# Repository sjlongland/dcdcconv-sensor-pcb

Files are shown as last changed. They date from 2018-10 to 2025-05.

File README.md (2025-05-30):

[Find this project on codeberg](https://codeberg.org/sjlongland/dcdcconv-sensor-pcb)

As a result of Github's decision to force AI-generated issues with no opt-out,
I am migrating personal projects of mine to Codeberg.  The project at Github
will be archived.

----

# Voltage/Current sensor board

This is a differential I²C voltage and current sensing board using the TI
INA219 power monitor IC and the NXP PCA9615 differential I²C controller.  This
is intended to provide a high-accuracy voltage and current measurement for the
[DC-DC converter
controller](https://codeberg.org/sjlongland/dcdcconv-controller-pcb).

There is a footprint for an on-board current shunt (e.g. TT Electronics
LRMAP5930B-R0002FT) as well as a connector for an off-board one.  The board
also has footprints for two screw terminal blocks (Phoenix Contact "Combicon"
1706785) to interface the board to up to 6AWG cables for power input/output.

Four two-way jumpers allow full freedom in selecting the I²C address used by
the INA219 according to combinations of settings chosen from its data sheet.

The underside has exposed copper areas to allow additional stranded cable to
be soldered over the traces to enhance the current carrying capability.

## Parts list

* C1, C3: 100nF ≥10V ceramic capacitor 0805 SMD (localised decoupling)
* C2: ≥100µF ≥10V electrolytic capacitor 6.3mm SMD (bulk decoupling)
* (**FIT ONE ONLY**) C4, C5, C6, C7: 100pF ≥20V ceramic capacitor (0V AC
  decoupling capacitor to chassis.  Choose the capacitor that best suits your
  mounting arrangements.)
* U1: NXP PCA9615 differential I²C controller.
* U2: TI INA219BIDR power monitor.
* R1, R6: (**NOT CONFIRMED**) 2k2 ohm 0805 SMD resistors (differential I²C
  pull-up)
* R4, R9: Spaces for additional pull-ups for differential I²C, do not fit
  unless found to be required.
* R5, R10: (**NOT CONFIRMED**) 2k2 ohm 0805 SMD resistors (differential I²C
  pull-down)
* R2, R7: Spaces for additional pull-downs for differential I²C, do not fit
  unless found to be required.
* R3, R8: (**NOT CONFIRMED**) 100 ohm 0805 SMD resistors (differential I²C
  termination)
* R12, R13: (**NOT CONFIRMED**) 2k2 ohm 0805 SMD resistors (I²C pull-up)
* J1: 6-pin 2.54mm "KK" connector (differential I²C bus)
* J2: 2-pin 2.54mm "KK" connector (external current shunt, **omit if fitting
  R11)

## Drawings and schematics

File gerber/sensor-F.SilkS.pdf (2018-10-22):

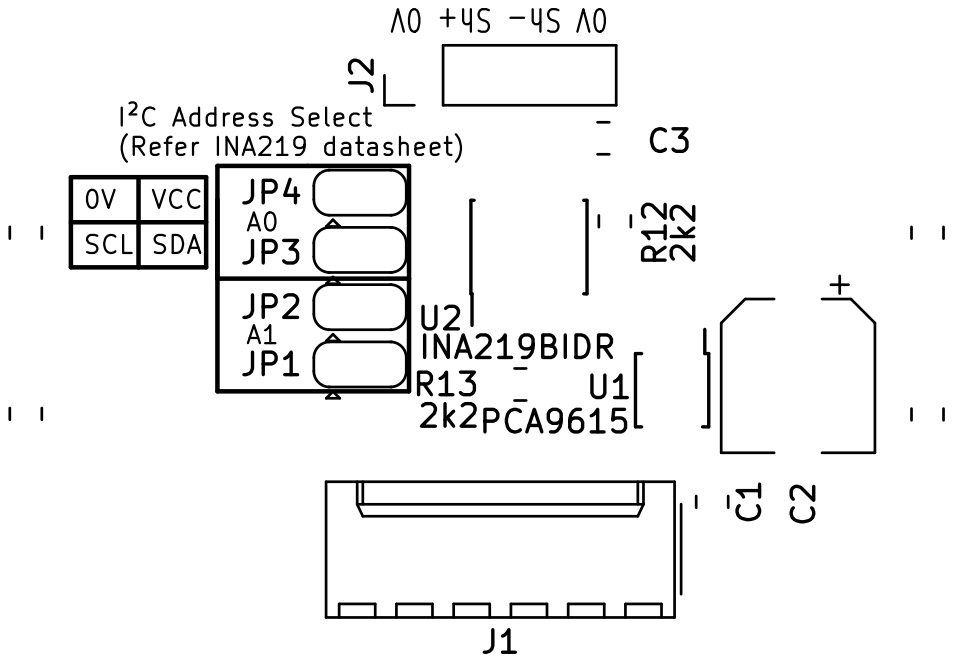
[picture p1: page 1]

0V | VCC | A1 A0 JP3
SCL | SDA

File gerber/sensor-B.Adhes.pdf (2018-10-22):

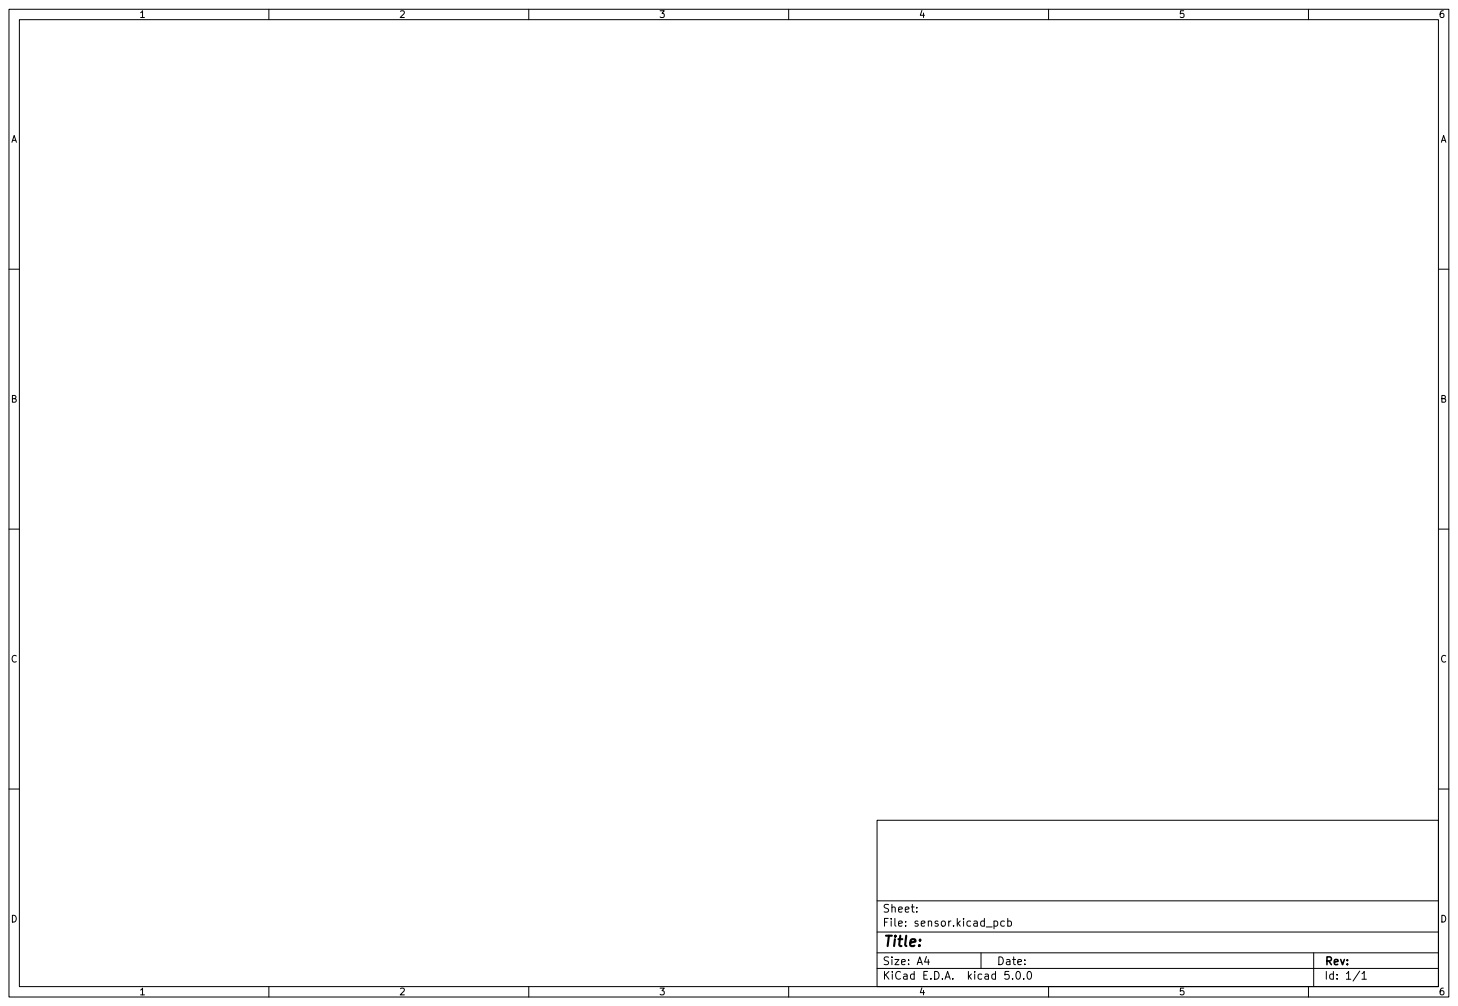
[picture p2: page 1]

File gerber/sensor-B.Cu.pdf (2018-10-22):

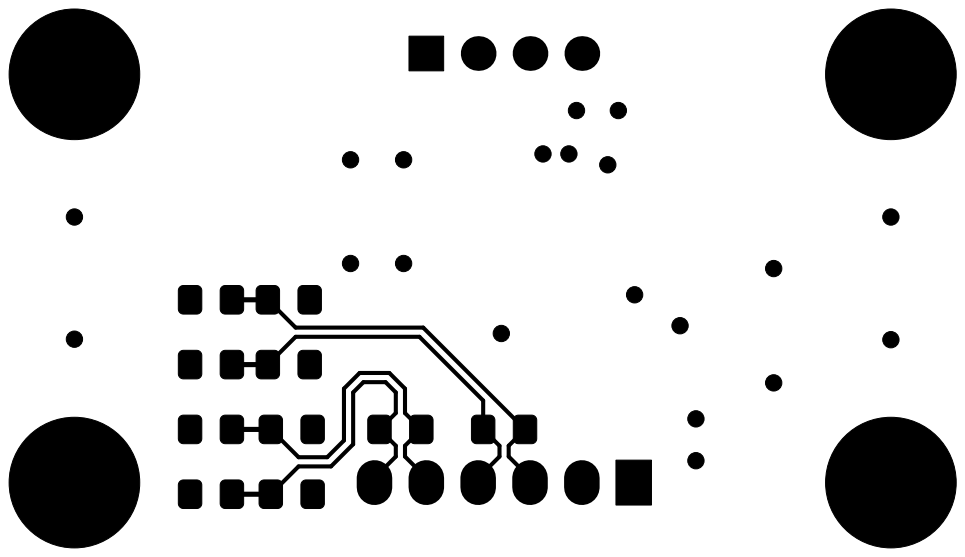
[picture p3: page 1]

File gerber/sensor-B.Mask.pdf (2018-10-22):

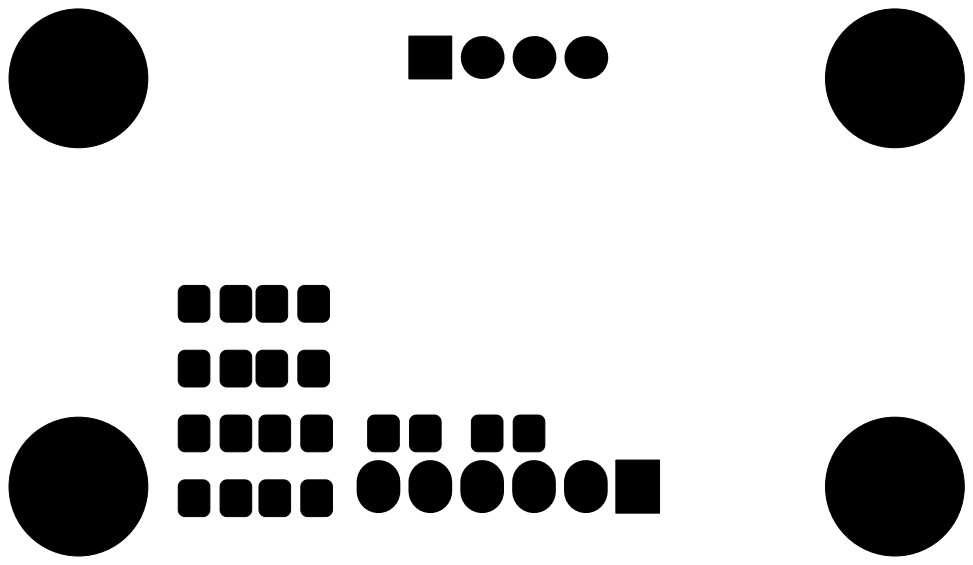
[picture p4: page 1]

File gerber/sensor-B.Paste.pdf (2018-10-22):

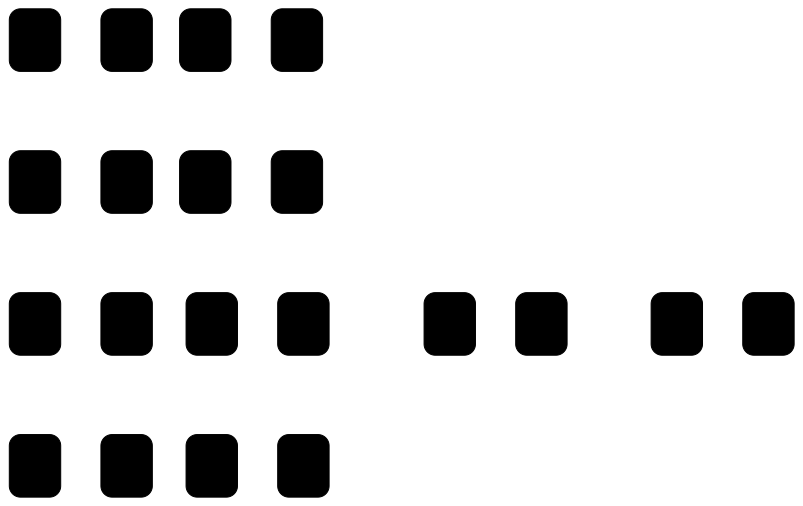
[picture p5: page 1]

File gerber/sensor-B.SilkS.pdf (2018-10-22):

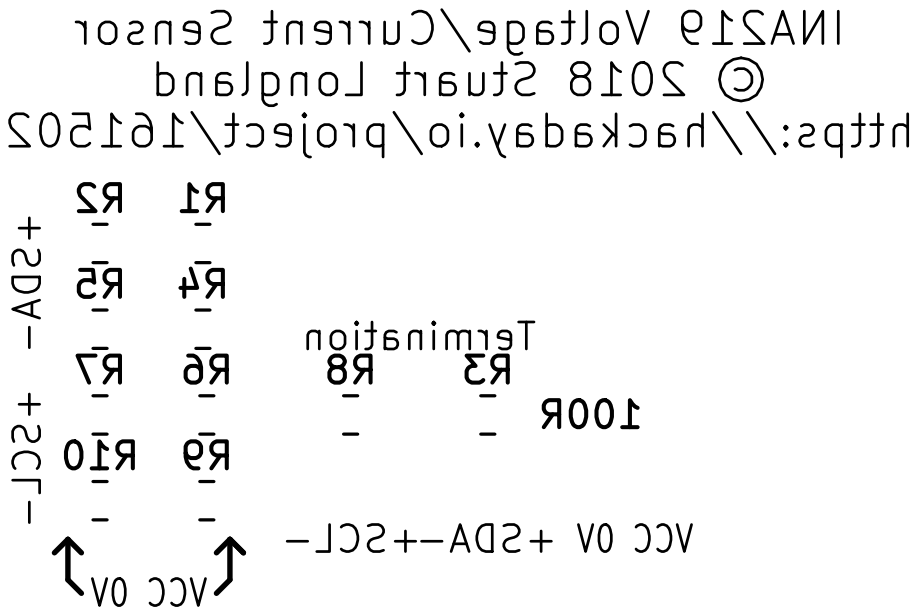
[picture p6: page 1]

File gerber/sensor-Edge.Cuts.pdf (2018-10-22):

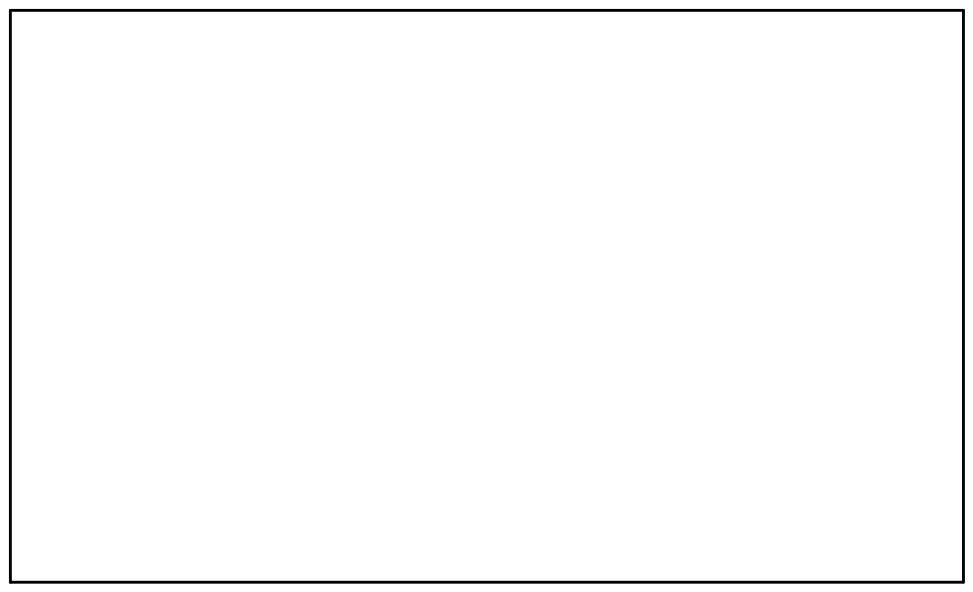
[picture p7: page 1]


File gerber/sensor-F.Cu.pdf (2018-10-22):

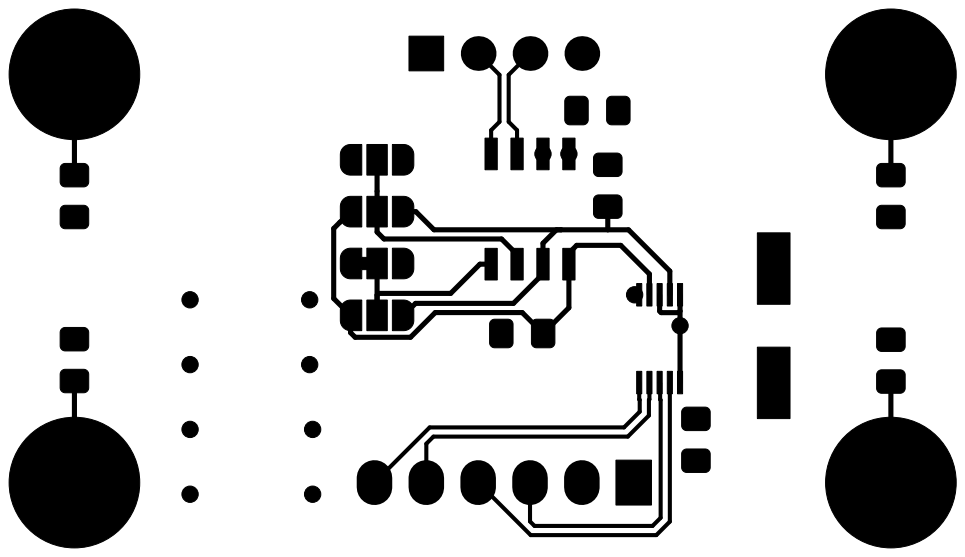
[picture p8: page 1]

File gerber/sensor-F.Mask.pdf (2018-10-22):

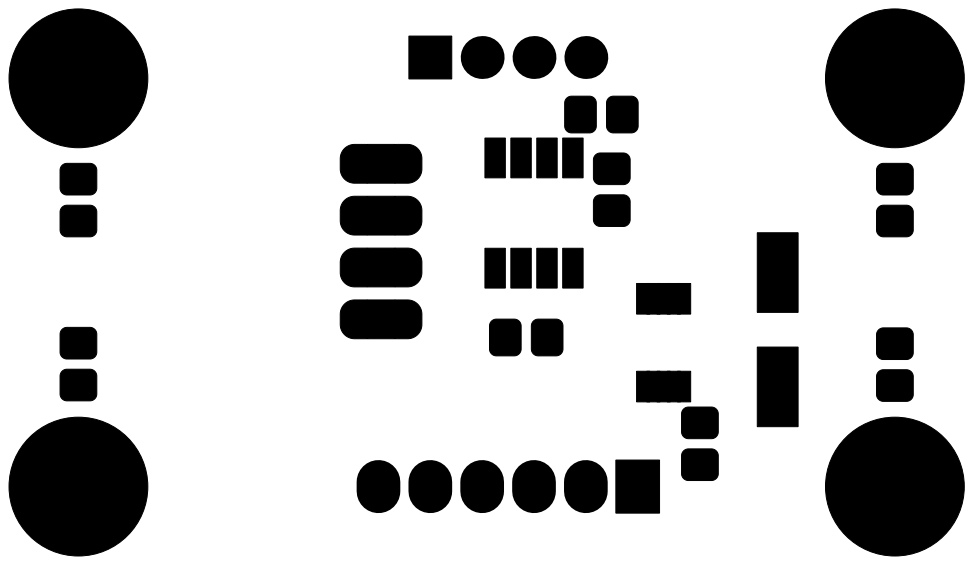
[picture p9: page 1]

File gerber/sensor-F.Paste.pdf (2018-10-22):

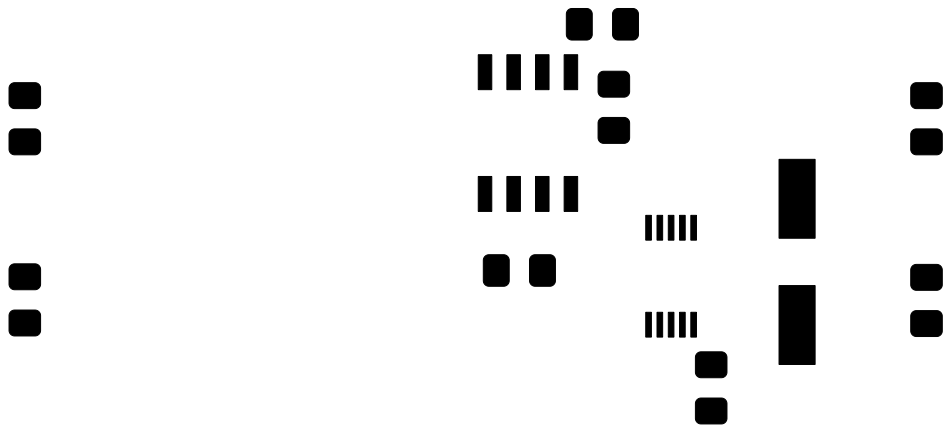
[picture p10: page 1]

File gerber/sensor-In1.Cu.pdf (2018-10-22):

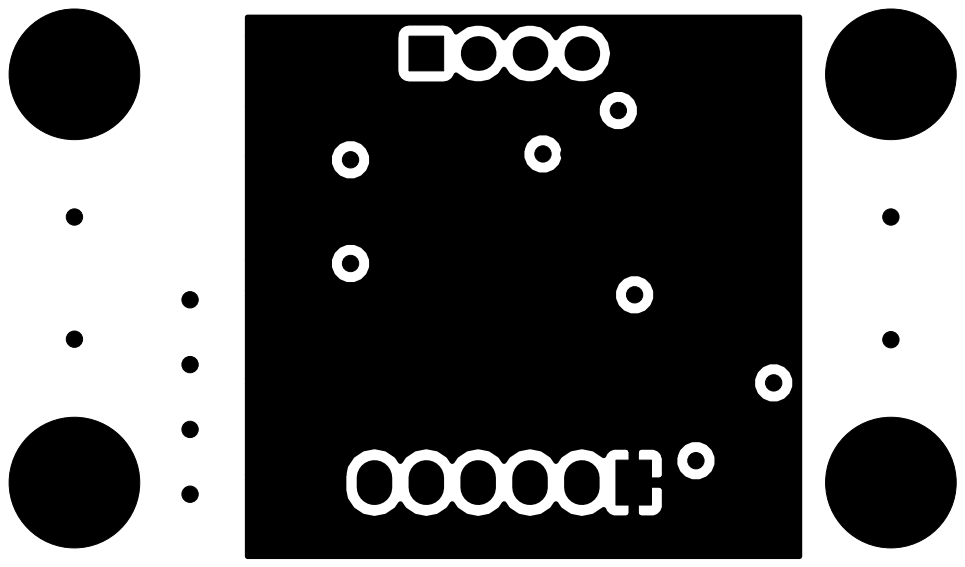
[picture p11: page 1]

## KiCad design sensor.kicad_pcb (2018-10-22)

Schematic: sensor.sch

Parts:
C1, C3: 100n; C_0805_2012Metric_Pad1.15x1.40mm_HandSolder
C2: 100u; CP_Elec_6.3x9.9
C4, C5, C6, C7: 100p; C_0805_2012Metric_Pad1.15x1.40mm_HandSolder
J1: CTRL; Molex_KK-254_AE-6410-06A_1x06_P2.54mm_Vertical
J2: Conn_01x04; PinHeader_1x04_P2.54mm_Vertical
JP1, JP3, JP4: SolderJumper_3_Open; SolderJumper-3_P1.3mm_Open_RoundedPad1.0x1.5mm
JP2: SolderJumper_3_Bridged12; SolderJumper-3_P1.3mm_Bridged12_RoundedPad1.0x1.5mm
MH1, MH2, MH3, MH4: MountingHole_Pad; MountingHole_3.2mm_M3_Pad_Via
R1, R2, R4, R5, R6, R7, R9, R10, R12, R13: 2k2; R_0805_2012Metric_Pad1.15x1.40mm_HandSolder
R3, R8: 100R; R_0805_2012Metric_Pad1.15x1.40mm_HandSolder
U1: PCA9615; TSSOP-10_3x3mm_P0.5mm
U2: INA219BIDR; SOIC-8_3.9x4.9mm_P1.27mm

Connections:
/A0: JP3.2, JP4.2, U2.2 (A0)
/A1: JP1.2, JP2.2, U2.1 (A1)
/SCL: JP1.1, JP3.1, R13.2, U1.4, U2.4 (SCL)
/SCL+: J1.5, R6.2, R7.1, R8.1, U1.7
/SCL-: J1.6, R8.2, R9.2, R10.1, U1.6
/SDA: JP1.3, JP3.3, R12.2, U1.2, U2.3 (SDA)
/SDA+: J1.3, R1.2, R2.1, R3.1, U1.8
/SDA-: J1.4, R3.2, R4.2, R5.1, U1.9
/SHUNT+: J2.2, U2.8 (IN+)
/SHUNT-: J2.3, U2.7 (IN–)
GND: C1.2, C2.2, C3.2, C4.2, C5.2, C6.2, C7.2, J1.2, J2.1, J2.4, JP2.1, JP4.1, R2.2, R5.2, R7.2, R10.2, U1.5, U2.6 (GND)
unnamed: C4.1, MH1.1
unnamed: C5.1, MH2.1
unnamed: C6.1, MH3.1
unnamed: C7.1, MH4.1
VCC: C1.1, C2.1, C3.1, J1.1, JP2.3, JP4.3, R1.1, R4.1, R6.1, R9.1, R12.1, R13.1, U1.1, U1.3, U1.10, U2.5 (VS)

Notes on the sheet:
I²C Address selection

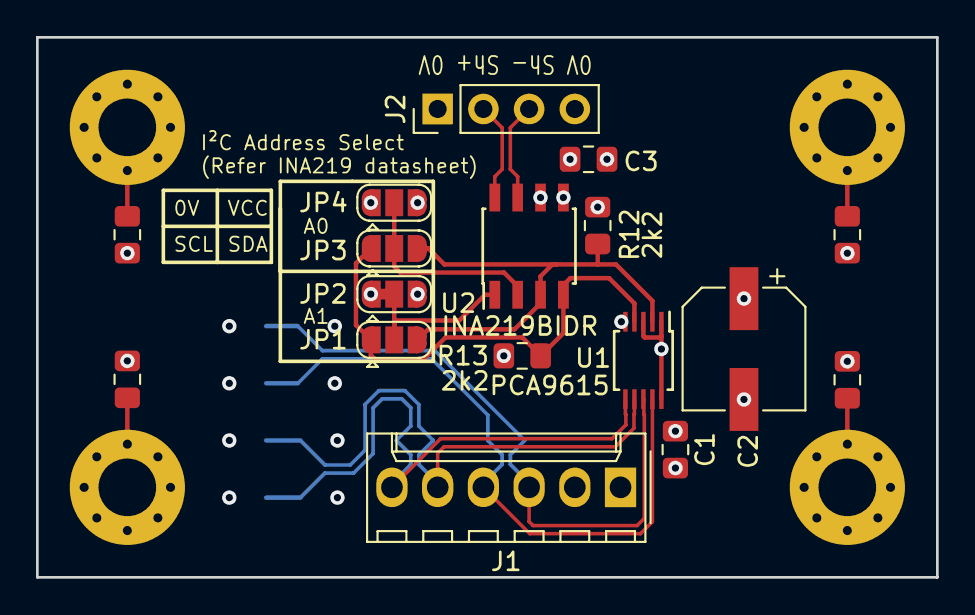
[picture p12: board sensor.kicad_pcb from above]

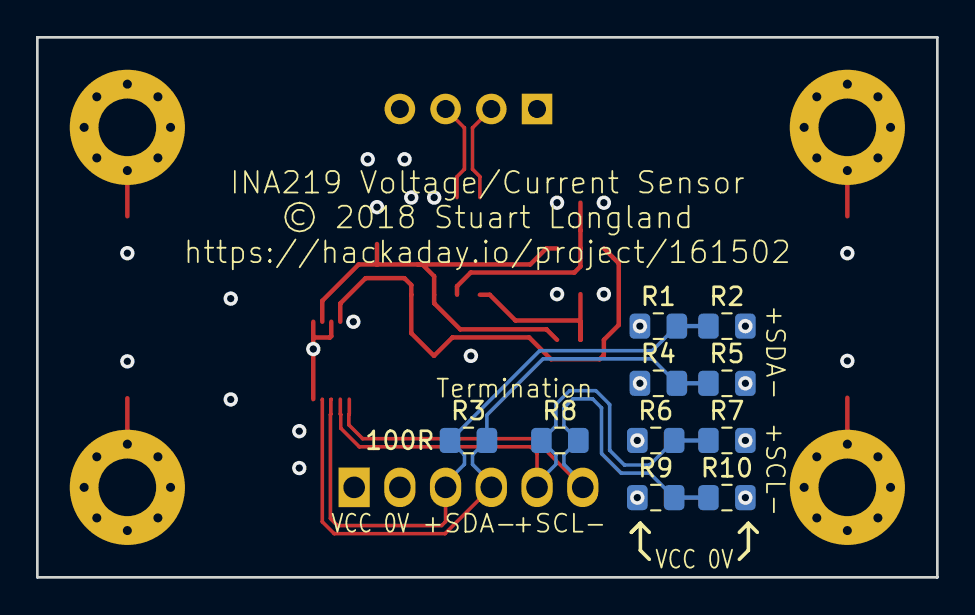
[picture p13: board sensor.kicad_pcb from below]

Board: 4 copper layers, 50.0 x 30.0 mm, 31 parts (10 on the bottom side), 16 nets.

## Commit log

2018-10-22 pcb, sch: Drop screw terminals, current shunt.
    [sensor.kicad_pcb, sensor.sch]
2018-10-22 gerber: Add CAM production files.
    [sensor-B.Cu.gbl, sensor-B.Mask.gbs, sensor-B.Paste.gbp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]

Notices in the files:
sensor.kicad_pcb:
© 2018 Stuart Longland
